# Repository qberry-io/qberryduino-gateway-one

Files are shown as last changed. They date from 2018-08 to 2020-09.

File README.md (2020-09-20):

# Qberryduino One v.1.0.0

"Qberryduino One" is an open source IOT Gateway developed for bringing telemetry-kind data to TCP Socket server over GPRS. 

It can be used as a gateway (Home Automation projects for example) as well as stand-alone Vehicle / Asset Tracker.

If wanted to use as a basic Vehicle / Asset Tracker, it's ready to use. No development needed.

## Prerequisites
The hardwares needed to use this solution.
* 1 * Arduino Mini Pro 16 MHz, 5v with Atmega328P (or equivalent version of Arduino)
* 1 * [Adafruit Fona 808 Version 2 Shield](https://www.adafruit.com/product/2636)
* 1 * USB to TTL Adaptor (Compatible with 3,3v)
* 1 * Red LED
* 1 * Yellow LED
* 1 *  Blue LED
* 3 * 220 ohm 5% resistors
* 1* GPS Antenna (uFL - 15x15 mm 1 dBi)
* 1* GSM Antenna (Compatible with Fona 808)
* 1* 3.7 V 950 mAh 25C Li-Po Battery
* 1* Active GPRS enabled Simcard

## Installation

These instructions will get you a copy of the project up and running on your development environment.

### Hardware installation

Here is a list of hardware and their connections step by step with preferred cable colors.
*	Red LED
	* (+) → Pin 5 (Red)  _(With a 250 ohm resistor)_
	* (-) → GND (Black)
*	Yellow LED
	*	(+) → Pin 4 (Yellow)  _(With a 250 ohm resistor)_
	*	(-) → GND (Black)
*	Blue LED
	*	(+) → Pin 2 (Blue)  _(With a 250 ohm resistor)_
	*	(-) → GND (Black)
*	Fona 808
	*	5v -> Pin 5v (Red)
	*	GND -> GND (Black)
	*	RX -> Pin 7 (Orange)
	*	TX -> Pin 8 (Brown)

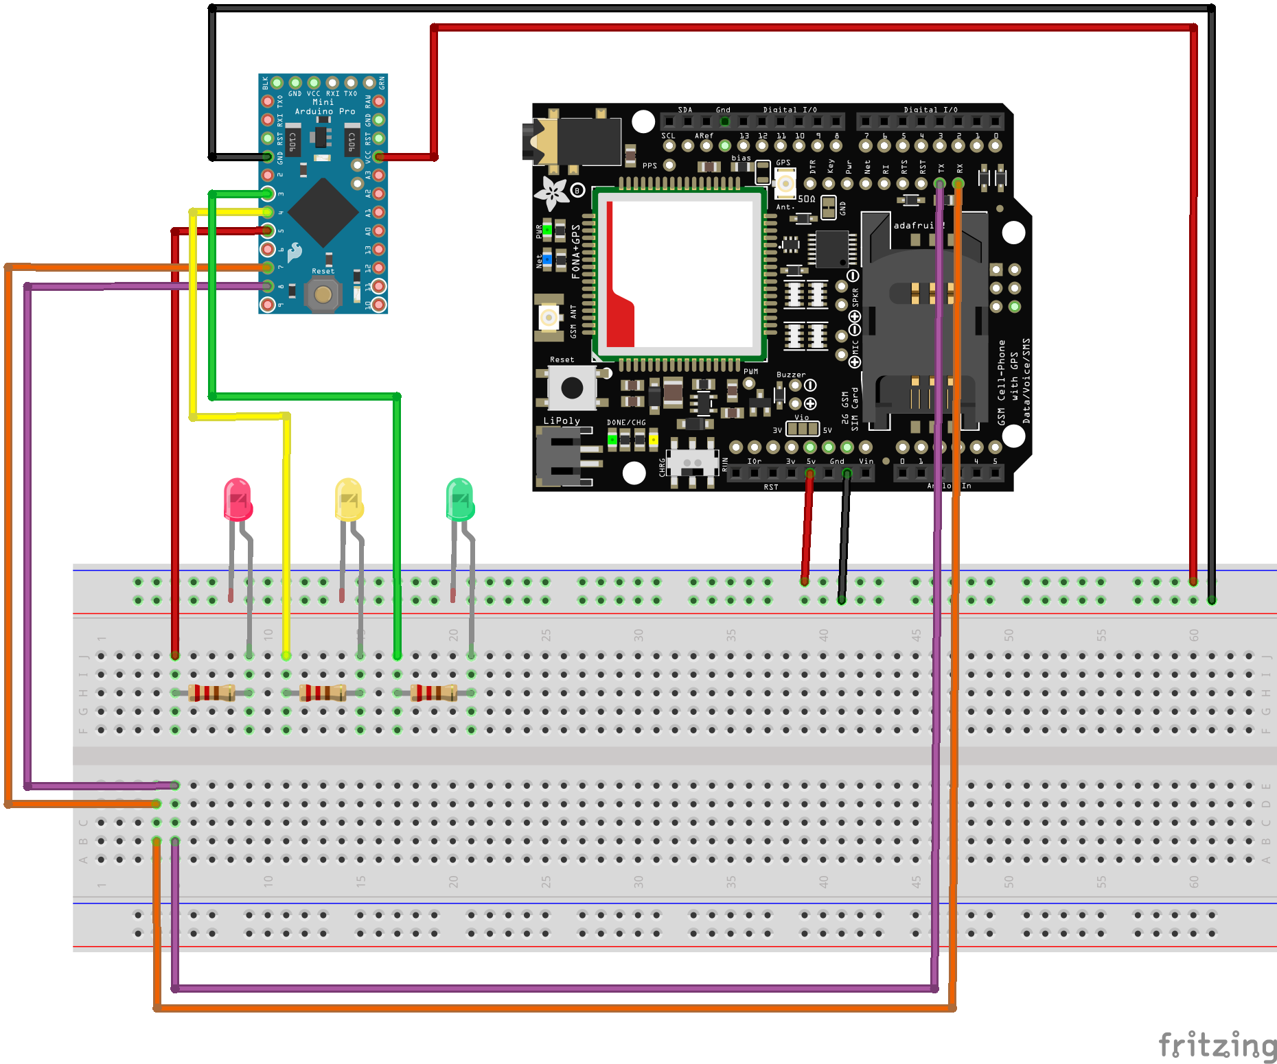
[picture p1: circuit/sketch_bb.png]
The sketch of the circuit


#### Notice for the PIN number of simcard
Please be sure that simcard doesn't protected with a PIN number. Fona 808 fails if the simcard has a PIN number.

#### Notice for the registration of Fona 808
Please be sure that IMEI number of Fona 808 is registered for your country.

#### Notice for the USB to TTL Adapter and its voltage value
Please be sure that the adapter provides the same voltage with the Arduino that you will use.
For example: If you will use an "Arduino Mini Pro 16 MHz, 5v with Atmega328P". you need to be sure it provides 5v output.

### Some configuration on code
There are two blocks of definitions needed to be configured in "qberryduino.ino". These are the informations of the target TCP Socket server and APN configurations of the current SIM line.
```
// Definitions of the target TCP Socket server.
char SERVER_ADDRES [] = "your_ip";
const PROGMEM int TCP_PORT = 13101;

// This is not a secret or password for accessing the
// TCP Socket Server.
// It lets you filter the illegal messages. Then, you can block
// them in your TCP Socket server.
// NOTICE: If you will use it on a common platform like qberry.io,
// it's strongly recommended you to change this secret key.
char SECRET[7] = "B23a56";
```
```
// Definitions of APN.
// NOTICE: To get your APN information, please refer to your Telecom
// company.
const PROGMEM String APN_NAME = "internet";
char APN_USER [] = "";
char APN_PASS [] = "";
```
#### An important notice for Compiling and Uploading the Sketch
Please be sure that you're compiling for the right microcontroller.
For example: If you will use an "Arduino Mini Pro 16 MHz, 5v with Atmega328P" you need to be sure;
* "ATmega328P (5v, 16MHz)" is selected on "Arduino IDE > Tools > Processor"
* "Arduino Pro or Pro Mini" is selected on "Arduino IDE > Tools > Board"
* The right port is selected on "Arduino IDE > Tools > Port"

### Common issues when the first runnings
Problem: It restarts recursively, when it comes to TCP Connection step.
Device restarts if the establishing a connection has failed. Please be sure;
* The APN information is correct,
* The target TCP Socket Server information is correct,
* The target TCP Socket Server is active and reachable over the firewall, IP table etc.

Problem: It restarts recursively, when it comes to Send step.
Device restarts if the established connection has droped and sending the message has failed. Please be sure,
* The target TCP Socket Server doesn't drop the connection.
* If you use a common platform like qberry.io, please be sure that the device is already defined to your account, licence is not expired and the password is correct. 

## Messaging Protocol
Please refer [Open Qberry Messaging Protocol](https://github.com/denizkanmaz/qberry-open-protocol)

## Known issues and missing important functions
After the development, there are some technical issues as well as some missing functions showed themselves. They will be solved with the incoming versions.

* Impossible to change the configurations remotely,
* A couple of dirty blocks of code (Parsing.cpp for examle).
* Some missed comments / documentation on code.

## Versioning

Used [SemVer](http://semver.org/) for versioning. For the versions available, see the [tags on this repository](https://github.com/denizkanmaz/qberryduino-gateway-one/tags). 

## Authors

* **[Deniz Kanmaz (denizkanmaz@gmail.com)](https://github.com/denizkanmaz)** - *Initial work* - [qberry.io](https://qberry.io)

## License

This project is licensed under the GNU General Public License v3 - see the [LICENSE.md](LICENSE.md) file for details.

NOTICE: This program is distributed in the hope that it will be useful, but WITHOUT ANY WARRANTY; without even the implied warranty of MERCHANTABILITY or FITNESS FOR A PARTICULAR PURPOSE.

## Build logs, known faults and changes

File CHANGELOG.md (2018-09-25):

# Changelog
All notable changes to this project will be documented in this file.

## Versioning
Used [SemVer](http://semver.org/) for versioning. For the versions available, see the [tags on this repository](https://github.com/denizkanmaz/qberry-open-protocol-parsing-dotnet/tags). 

## [1.0.0-beta1] - 2018-08-10
### Initial beta version

## [1.0.0] - 2018-09-25
### Added
- "CHANGELOG.md" file.
- Added "Nuget.org feed page" and "Github Release page" links to the "README.md" file.

### Changed
- Changed protocol version in MessageFactoryBase and "Readme.md".

### Fixes
- Can not realize lost connections.

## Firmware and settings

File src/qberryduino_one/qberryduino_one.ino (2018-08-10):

//  Copyright (c) 2018-present, Deniz Kanmaz. All rights reserved.
//  This source code is licensed under the GNU GENERAL PUBLIC
//  LICENCE V3. Use of this source code is governed by a license
//  that can be found in the LICENSE file.

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
//  E-mail: denizkanmaz@gmail.com

//  Description: "Qberyduino One" is an open source IOT Gateway
//  developed for bringing telemetry-kind data to TCP Socket
//  server over GPRS.

//  Model: Qberyduino One
//  Version: 1.0.0-beta1

#include "MainSerial.h"
#include "LED.h"
#include "Modem.h"
#include "Parsing.h"
#include "RandomString.h"

// Including the message factories
#include "GNSSMessageFactory.h"
#include "BatteryMessageFactory.h"
#include "HolaMessageFactory.h"
// #include "MyLovelyMessageFactory.h"

// Definitions of necessary utilities.
LED _led;
MainSerial _mainSerial;
Modem _modem;
Parsing _parsing = Parsing();
RandomString _rndStr = RandomString();

// Instances of message factories.
GNSSMessageFactory _gnssMF = GNSSMessageFactory();
BatteryMessageFactory _battMF = BatteryMessageFactory();
HolaMessageFactory _holaMF = HolaMessageFactory();
// MyLovelyMessageFactory _myLovelyMF = MyLovelyMessageFactory();

// Definitions of the target TCP Socket server.
char SERVER_ADDRES [] = "your_ip";
const PROGMEM int TCP_PORT = 13101;

// This is not a secret or password for accessing the
// TCP Socket Server.
// It lets you filter the illegal messages. Then, you can block
// them in your TCP Socket server.
// NOTICE: If you will use it on a common platform like qberry.io,
// it's strongly recommended you to change this secret key.
char SECRET[7] = "B23a56";

// Definitions of APN.
// NOTICE: To get your APN information, please refer to your
// Telecom company.
const PROGMEM String APN_NAME = "internet";
char APN_USER [] = "";
char APN_PASS [] = "";

// Definitions of development / maintenance stuffs
const PROGMEM boolean DEBUG_MODE = true;
const PROGMEM int SERIAL_BAUD_RATE = 9600;

// Definitions of device
const PROGMEM byte DEVICE_IDENTITY_LENGTH = 18;
char DEVICE_IDENTITY_PREFIX[] = "90";
char DEVICE_MODEL[] = "ONE";

const PROGMEM byte CONNECTION_ID_LENGTH = 7;

// Definitions of leds
const PROGMEM byte LED_PINS_LENGTH = 4;
byte LED_PINS[LED_PINS_LENGTH] = { 5, 4, 3, 2 };

// Definitions of modem
const PROGMEM byte MODEM_RX_PIN = 8;
const PROGMEM byte MODEM_TX_PIN = 7;
const PROGMEM int MODEM_BAUD_RATE = 9600;

// Definitions of Intervals and Delays
const PROGMEM int CURR_INTERVAL = 15000;
const PROGMEM int STARTUP_DELAY = 5000;

// Current State
int i; // Used in loops only
unsigned long now = 0;
unsigned long lastCurrTime = 0;
char connectionId[CONNECTION_ID_LENGTH];
char deviceIdentity[DEVICE_IDENTITY_LENGTH];

// Resets the device.
void(* reset) (void) = 0;

// Sends the given String message to the server.
void sendToServer(String msg) {

  // Send the message to the server.
  if (_modem.sendToServer(msg)) {
    _led.indicateTCPSendSuccess();
  } else {

    _led.indicateDisconnected();
    _led.indicateTCPSendFailed();
    // Reset the device if the sending operation has failed.
    // (This happens when the established connection has
    // corrupted.)
    reset();
  }
}

void setup() {

  // Initialize the main serial if debug mode enabled.
  if (DEBUG_MODE) {
    _mainSerial.init(SERIAL_BAUD_RATE);
  }

  // Initialize LED indicators.
  _led.init(LED_PINS,
            LED_PINS_LENGTH);

  // Indicate for "Starting Up!".
  _led.indicateStarting();

  // Indicate for "Powered On".
  _led.indicatePoweredOn();

  // Initialize the pseudo-random number generator.
  randomSeed(analogRead(0));

  // Give the modem some time.
  delay(STARTUP_DELAY);

  // Initilize the modem.
  _modem.init(MODEM_RX_PIN,
              MODEM_TX_PIN,
              MODEM_BAUD_RATE,
              APN_NAME, APN_USER,
              APN_PASS,
              _mainSerial);

  // Connect to the TCP server..
  if (!_modem.connectToTCP(SERVER_ADDRES,
                           TCP_PORT)) {

    // Indicate establishing connection has failed.
    _led.indicateConnectionError();

    // reset the device if the establishing connection has
    // failed.
    reset();
    return;
  }

  // Indicate successfuly connected.
  _led.indicateConnected();

  // Initializing a new headerId.
  _rndStr.generate(CONNECTION_ID_LENGTH - 1).toCharArray(connectionId, CONNECTION_ID_LENGTH);

  // Set device identity using DEVICE_IDENTITY_PREFIX and
  // IMEI of the Modem.
  (String(DEVICE_IDENTITY_PREFIX)
   + String(_modem.getImei())).toCharArray(
     deviceIdentity,
     DEVICE_IDENTITY_LENGTH);

  // Send a "HOLA" message to the server.
  processToSendHOLA();

  _parsing.clear();
  _modem.clearBuffer();
}

// 1-) Creates "HOLA" message,
// 2-) Sends it to the server.
void processToSendHOLA() {
  sendToServer(_holaMF.create(deviceIdentity,
                              connectionId,
                              SECRET,
                              DEVICE_MODEL));
}

// 1-) Gets the current CGNSS data,
// 2-) Parses it,
// 3-) Creates "GNSS" message,
// 4-) Sends it to the server.
void processToSendCurrentCGNSS() {
  sendToServer(_gnssMF.create(deviceIdentity,
                              connectionId,
                              _parsing.parseNMEAData(
                                _modem.getCGNSSData())
                             ));
  _parsing.clear();
  _modem.clearBuffer();
  delay(1000);
}

// 1-) Gets the current Battery data,
// 2-) Parses it,
// 3-) Creates "BATT" message,
// 4-) Sends it to the server.
void processToSendCurrentBatteryStat() {
  sendToServer(_battMF.create(deviceIdentity,
                              connectionId,
                              _parsing.parseBatt(
                                _modem.getBatteryStat()
                              )));
  _parsing.clear();
  _modem.clearBuffer();
  delay(1000);
}

void loop() {

  now = millis();

  // If it's time to send a "Current State" message...
  if (now > (lastCurrTime + CURR_INTERVAL)) {
    lastCurrTime = millis();

    // Process to send current CGNSS state to the server.
    processToSendCurrentCGNSS();

    // Process to send current Battery state to the server.
    processToSendCurrentBatteryStat();

    // Process to send my lovely data to the server.
    // processMyLovelyData();
  }
}

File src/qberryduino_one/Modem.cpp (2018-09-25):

//  Copyright (c) 2018-present, Deniz Kanmaz. All rights reserved.
//  This source code is licensed under the GNU GENERAL PUBLIC
//  LICENCE V3. Use of this source code is governed by a license
//  that can be found in the LICENSE file.

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
//  E-mail: denizkanmaz@gmail.com

//  Description: Please refer to "Modem.h".

#include "Modem.h"
#include "Arduino.h"

// Clears the serial buffer.
void Modem::clearSerial() {
  while (ss.available() > 0) {
    ss.read();
  }
}

// Prints given string to the MainSerial (For dubugging).
void Modem::printReceived(String text) {
  mainSerial.println(text);
}

// Prints given string to the MainSerial (For dubugging)
void Modem::printSent(String text) {
  mainSerial.println(text);
}

// Returns whether the given character is a special character.
boolean Modem::isSpecialChar(char chr) {
  return ichr == '\r'
         || ichr == '\n'
         || ichr == '\0'
         || ichr == '\b'
         || ichr == '\a'
         || ichr == '\f'
         || ichr == '\t'
         || ichr == '\v';
}

// Writes given message to the Modem over the Serial.
String Modem::write(String message, int delayer) {
  clearSerial();
  clearBuffer();

  ss.print(message);
  ss.write(0x1A);
  printSent(message);
  delay(delayer);

  i = 0;
  while (ss.available() != 0) {

    ichr = ss.read();
    if (!isSpecialChar(ichr)) {
      ssBuffer = (ssBuffer + ichr);
      i++;
    }

  }
  printReceived(ssBuffer);
  return ssBuffer;
}

// Writes given message to the Modem and leave a break
// over the Serial.
// TODO: Let them use WriteLine2!
String Modem::writeLine(String message, int delayer) {
  clearSerial();
  clearBuffer();

  ss.println(message);
  printSent(message);
  delay(delayer);

  i = 0;
  while (ss.available() != 0) {

    ichr = ss.read();
    // printReceived((String)chr);
    if (!isSpecialChar(ichr)) {
      ssBuffer = (ssBuffer + ichr);
      i++;
    }

  }
  printReceived(ssBuffer);
  return ssBuffer;
}

// Writes given message to the Modem and leave a break
// over the Serial.
char * Modem::writeLine2(String message, int delayer) {
  clearSerial();
  ss.println(message);
  printSent(message);
  delay(delayer);

  static char ssBuffer2 [SS_BUFFER_SIZE];

  i = 0;
  while (ss.available() != 0) {
    ichr = ss.read();
    if (!isSpecialChar(ichr)) {
      ssBuffer2[i] = ichr;
      i++;
    }
  }
  printReceived(ssBuffer2);
  return ssBuffer2;
}

// Initializes the object and gets the Modem ready for commands
// over the Serial.
void Modem::init(byte rx,
                 byte tx,
                 int baudRate,
                 String apnN,
                 char apnUsername[],
                 char apnPass[],
                 MainSerial ms) {

  apnName = apnN;
  apnUser = apnUsername;
  apnPassword = apnPass;

  // ssBuffer.reserve(SS_BUFFER_SIZE);

  ss = SoftwareSerial(rx, tx);
  ss.begin(baudRate);
  mainSerial = ms;
  delay(100);

  writeLine(at.begin(), DELAY_1000);
  writeLine(at.resetToFactoryDefault(), DELAY_2000);
  writeLine(at.begin(), DELAY_1000);
  writeLine(at.disableEcho(), DELAY_1000);

  delay(500);
}

// Clears the buffered data on MC's memory.
void Modem::clearBuffer() {
  ssBuffer = "";
}

// Gets the imei of the mobile terminal.
char* Modem::getImei() {
  return imei;
}

// Gets the current CGNSS data from the module.
char * Modem::getCGNSSData() {
  return writeLine2(at.getCGNSSData(), DELAY_60);
}

// Gets the current battery data from the module.
char * Modem::getBatteryStat() {
  return writeLine2(at.getBatteryStat(), DELAY_250);
}

// Makes a TCP connection to given address and port.
boolean Modem::connectToTCP(char address[], int port) {
  writeLine(at.setResultMode(2), DELAY_250);
  delay(DELAY_250);

  String(writeLine(
           at.getImei(),
           DELAY_250)).substring(0, 16)
  .toCharArray(imei, 16);

  delay(DELAY_250);
  writeLine(at.closeTCP(), DELAY_250);
  delay(DELAY_250);
  writeLine(at.resetIPSession(), DELAY_250);
  delay(DELAY_250);
  writeLine(at.enableGNSS(), DELAY_250);
  delay(DELAY_250);
  writeLine(at.setCGNSSequence(), DELAY_250);
  delay(DELAY_250);
  writeLine(at.setConnectionModeSingle(), DELAY_250);
  delay(DELAY_7000);
  writeLine(at.setupPDPContext(apnName,
                               apnUser,
                               apnPassword), DELAY_2000);
  delay(DELAY_3000);
  writeLine(at.attachGPRS(), DELAY_3000);
  delay(DELAY_3000);
  writeLine(at.bringGPRSCalls(), DELAY_1000);
  delay(DELAY_3000);
  writeLine(at.getLocalIP(), DELAY_3000);
  delay(DELAY_250);

  if (writeLine(at.startTCPConnection(address, (String) port),
                DELAY_3000).lastIndexOf(F("CONNECT OK")) > -1) {
    delay(DELAY_250);
    return true;
  } else {
    delay(DELAY_250);
    return false;
  }
}

// Sends given message to the server.
// NOTICE: The message must be formatted using "Messaging" utility.
// And the version of the "Parser" utility that running on the server
// must be supported the current version of protocol.
boolean Modem::sendToServer(String msg) {
  boolean success = writeLine(at.activateCIPSendMode(),
                              DELAY_1000)
                    .lastIndexOf(F("not allowed")) == -1;
  if (success) {
    write(msg, DELAY_250);
  }

  return success;
}

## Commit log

2018-07-29 Added a sketch of the circuit
    [sketch.fzz]
2018-08-06 Wrong Hola message format has been fixed
    [qberryduino_one.ino]
2018-09-25 Bugfix - Can not realize when the connection lost
    [Modem.cpp]
